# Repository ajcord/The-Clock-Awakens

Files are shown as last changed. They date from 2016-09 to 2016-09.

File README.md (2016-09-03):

The Clock Awakens
=================

Using LEDs and an ESP8266 to make a smart, futuristic Star Wars clock

See [the project page](https://hackaday.io/project/7681-the-clock-awakens)
for details such as the parts list, building instructions, etc.

Uses the [Sunrise-Sunset API](http://sunrise-sunset.org/api) among others.

Setting up the environment
--------------------------

1. Set up the ESP8266 in the Arduino IDE
   ([instructions](https://github.com/esp8266/Arduino))
2. Install the [Time](https://github.com/PaulStoffregen/Time),
   [Adafruit NeoPixel](https://github.com/adafruit/Adafruit_NeoPixel),
   [WiFiManager](https://github.com/tzapu/WiFiManager), and
   [ESP8266Scheduler](https://github.com/nrwiersma/ESP8266Scheduler)
   libraries through the Library Manager
   ([instructions](https://www.arduino.cc/en/Guide/Libraries#toc3))
3. Install the
   [ESP8266FS tool](https://github.com/esp8266/arduino-esp8266fs-plugin)
   located in `lib`
   ([instructions](http://arduino.esp8266.com/versions/1.6.5-1160-gef26c5f/doc/reference.html#uploading-files-to-file-system))
4. Make the necessary changes to `src/firmware/config.h.template`
    and save them in `src/firmware/config.h`
5. Open `src/firmware/firmware.ino` in the Arduino IDE
6. Upload the sketch data by going to Tools > ESP8266 Sketch Data Upload
7. Upload the sketch to the device

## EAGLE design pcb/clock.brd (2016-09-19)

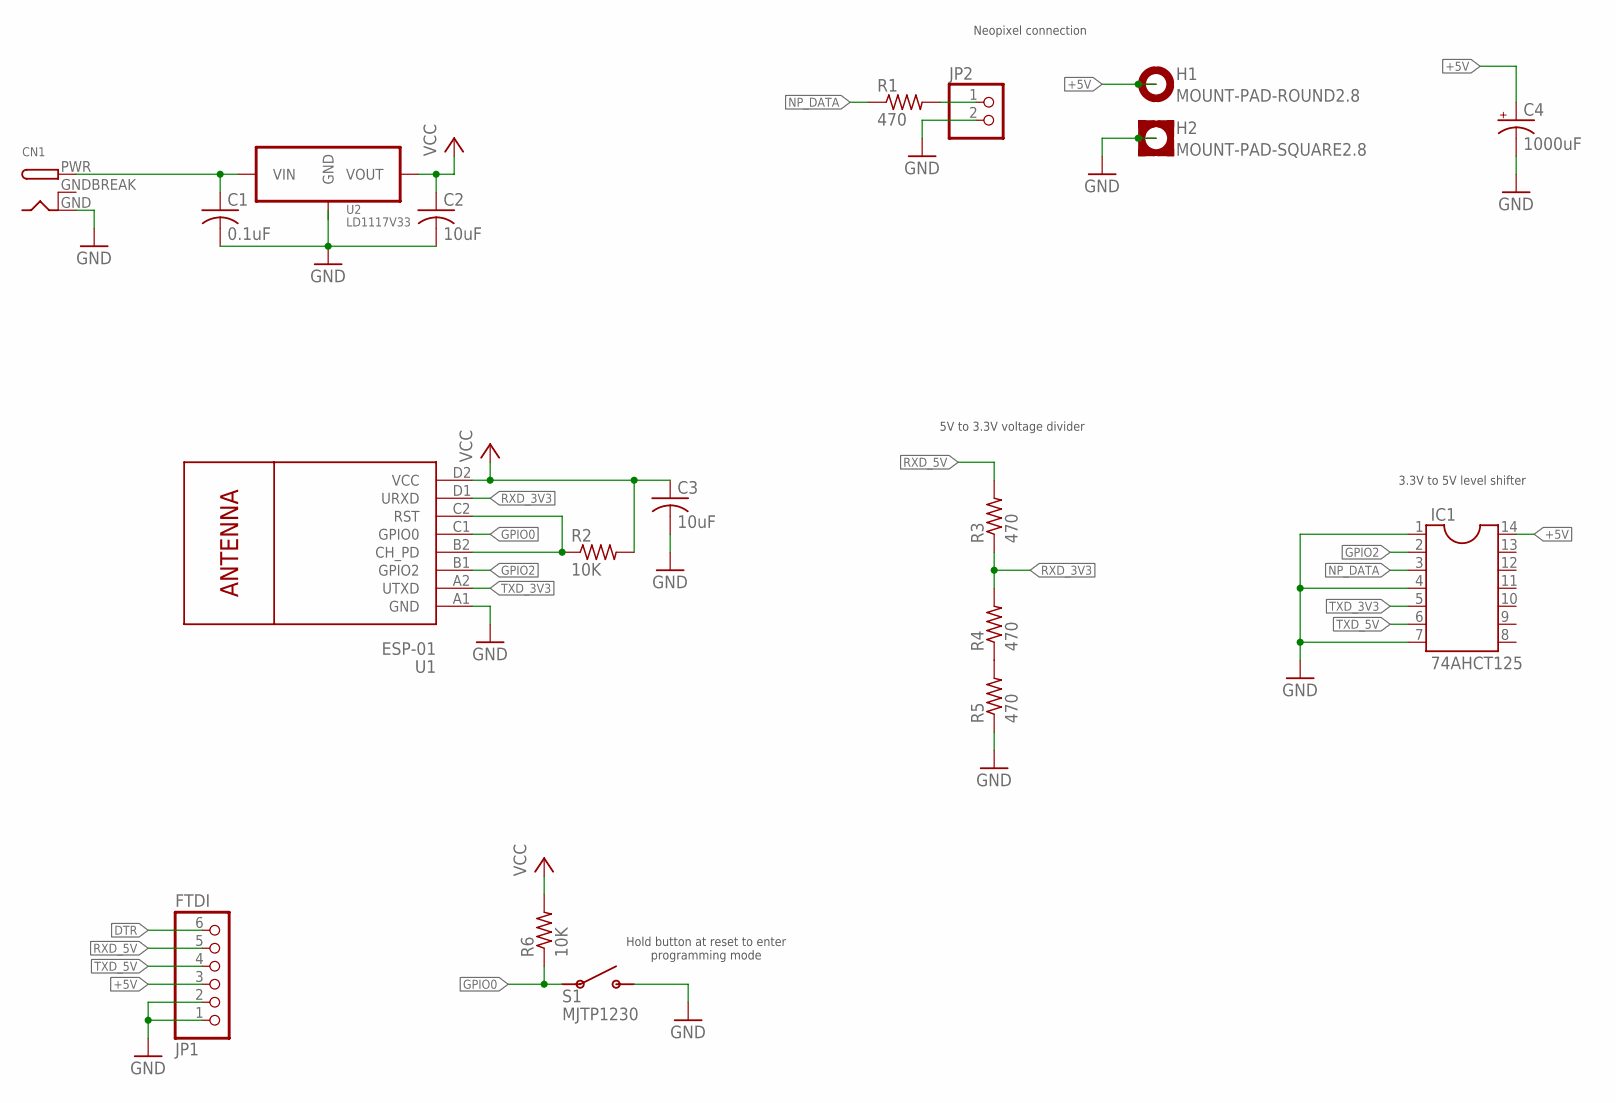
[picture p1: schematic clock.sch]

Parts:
C1: 0.1uF; C025-025X050
C2, C3: 10uF; C025-025X050
C4: 1000uF; E3,5-8
CN1: DCBARRELPTH; DCJACK_2MM_PTH
H1: MOUNT-PAD-ROUND2.8; 2,8-PAD
H2: MOUNT-PAD-SQUARE2.8; 2,8-PAD-SQUARE
IC1: 74AHCT125; DIL14
JP1: FTDI; 1X06/90
JP2: PINHD-1X2; 1X02
R1, R3, R4, R5: 470; 0207/10
R2, R6: 10K; 0207/10
S1: MJTP1230; TACTILE-BUTTON-MJTP1230
U1: ESP-01; WIRELESS-WIFI-ESP-01
U2: LD1117V33; TO-220

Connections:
+5V: C1.1, C4.+, CN1.PWR, H1.B2,8, IC1.14, JP1.3, U2.P$3 (VIN)
DTR: JP1.6
GND: C1.2, C2.2, C3.2, C4.-, CN1.GND, H2.B2,8, IC1.1, IC1.4, IC1.7, JP1.1, JP1.2, JP2.2, R5.1, S1.P$2 (3), S1.P$4 (3), U1.A1 (GND), U2.P$1 (GND)
GNDBREAK: CN1.GNDBREAK
GPIO0: R6.1, S1.P$1 (1), S1.P$3 (1), U1.C1 (GPIO0)
GPIO2: IC1.2, U1.B1 (GPIO2)
unnamed: JP2.1, R1.2
unnamed: R2.1, U1.B2 (CH_PD), U1.C2 (RST)
unnamed: R4.1, R5.2
NP_DATA: IC1.3, R1.1
RXD_3V3: R3.1, R4.2, U1.D1 (URXD)
RXD_5V: JP1.5, R3.2
TXD_3V3: IC1.5, U1.A2 (UTXD)
TXD_5V: IC1.6, JP1.4
VCC: C2.1, C3.1, R2.2, R6.2, U1.D2 (VCC), U2.P$2 (VOUT), U2.P$4 (VOUT)

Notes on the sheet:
Hold button at reset to enter programming mode
5V to 3.3V voltage divider
3.3V to 5V level shifter
Neopixel connection

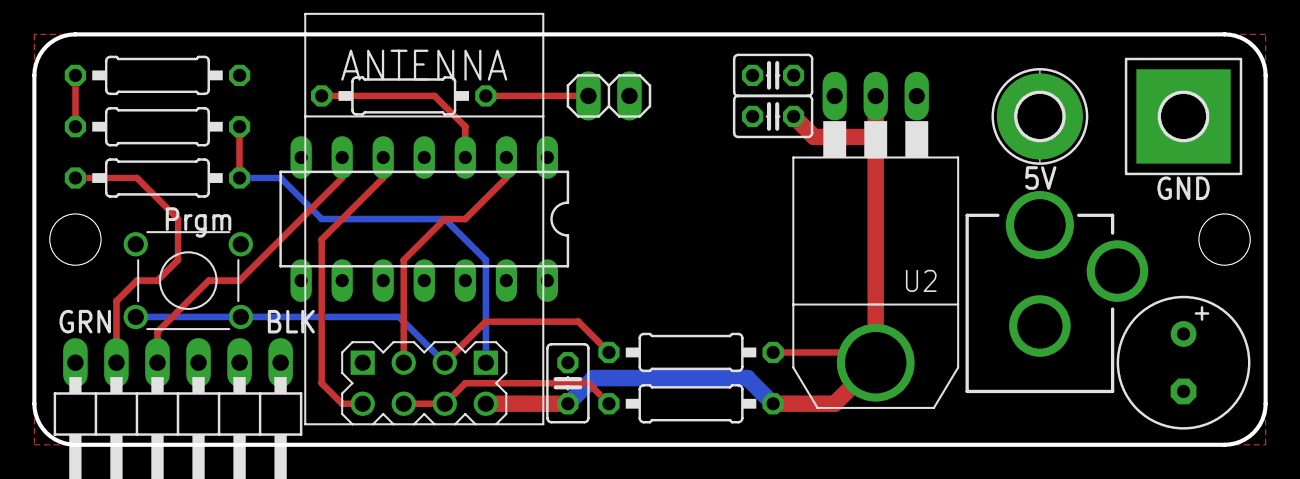
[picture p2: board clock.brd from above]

Board: 2 copper layers, 76.2 x 25.4 mm, 19 parts (0 on the bottom side), 13 nets.

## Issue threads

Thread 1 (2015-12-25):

Allow scheduled color schemes for certain dates

ajcord, 2015-12-25:
E.g. red, white, and blue on July 4th, red and green on Christmas, etc.

ajcord, 2015-12-30:
Could integrate with Google Calendar API to avoid reinventing the wheel

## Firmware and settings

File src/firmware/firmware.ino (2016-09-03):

/**
 * The Clock Awakens: an LED-ringed clock with WiFi
 * Author: Alex Cordonnier
 */

#include <ESP8266WiFi.h>
#include <DNSServer.h>
#include <ESP8266WebServer.h>
#include <ESP8266mDNS.h>
#include <WiFiManager.h>
#include <TimeLib.h>
#include <Adafruit_NeoPixel.h>
#include <EEPROM.h>
#include <Scheduler.h>

#include "config.h"
#include "DataStore.h"
#include "WebServer.h"
#include "Geolocation.h"
#include "InternetTime.h"
#include "ClockDisplay.h"

void setup() {

    delay(5000);
    Serial.begin(115200);
    Serial.print("\n\n");

    printMacAddress();

    WiFiManager wifiManager;
    wifiManager.autoConnect("Clock Setup");

    Serial.println("");
    Serial.println("Connected");

    printWiFiInfo();

    DataStore.begin();
    Geolocation.begin();
    InternetTime.begin(TIME_SERVER, SYNC_INTERVAL);

    Scheduler.start(&web_server_task);
    Scheduler.start(&clock_display_task);

    Serial.println("Ready. Starting scheduler.");

    Scheduler.begin();
}

// Dummy - handled by scheduler
void loop() { }

/**
 * Prints the ESP8266's MAC address for reference.
 */
void printMacAddress() {

    Serial.print("MAC address: ");

    unsigned char mac[WL_MAC_ADDR_LENGTH];
    WiFi.macAddress(mac);

    int i;
    for (i = 0; i < WL_MAC_ADDR_LENGTH - 1; i++) {
        Serial.print(mac[i], HEX);
        Serial.print(":");
    }

    Serial.println(mac[i], HEX);
}

/**
 * Prints info about the WiFi connection.
 */
void printWiFiInfo() {

    Serial.print("Local IP address: ");
    Serial.println(WiFi.localIP());

    Serial.print("Signal strength (RSSI): ");
    Serial.println(WiFi.RSSI());
}

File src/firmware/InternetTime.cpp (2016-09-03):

#include "InternetTime.h"
#include "Geolocation.h"
#include "DataStore.h"
#include <ESP8266WiFi.h>

#define UDP_IN_PORT         2390
#define NTP_OUT_PORT        123
#define TIMEOUT             2000 // ms

#define UNIX_TIME_OFFSET    2208988800UL // Number of seconds from 1900 to 1970
#define NTP_TO_MICROS_RATIO 4295 // Roughly (2^32 / 1000000)
#define PRECISION_TEST_NUM_ITERATIONS   100

// Leap indicator warning bits
enum {
    NTP_LI_NONE,    // No leap second
    NTP_LI_INSERT,  // Last minute has 61 seconds
    NTP_LI_DELETE,  // Last minute has 59 seconds
    NTP_LI_UNKNOWN,   // Clock not synchronized
} NTP_LI;

// NTP mode bits
enum {
    NTP_MODE_RESERVED,
    NTP_MODE_SYMMETRIC_ACTIVE,
    NTP_MODE_SYMMETRIC_PASSIVE,
    NTP_MODE_CLIENT,
    NTP_MODE_SERVER,
    NTP_MODE_BROADCAST,
    NTP_MODE_CONTROL_MESSAGE,
    NTP_MODE_RESERVED_PRIVATE,
} NTP_MODE;

uint32_t extractSeconds(uint64_t ntp) {

    return (uint32_t)((ntp >> 32) & 0xFFFFFFFF);
}

uint32_t extractFraction(uint64_t ntp) {

    return (uint32_t)(ntp & 0xFFFFFFFF);
}

double fixedToFloat(uint64_t ntp) {

    uint32_t seconds = extractSeconds(ntp);
    uint32_t fraction = extractFraction(ntp);

    return (double)seconds + (double)fraction/(1ULL << 32);
}

time_t updateTime() {
    return InternetTime.getTime();
}

void onTimezoneUpdate(DSKey key, int value) {

    Serial.println("Timezone updated!");
    time_t currentTime = updateTime();
    setTime(currentTime);
}

InternetTimeClass::InternetTimeClass() {

    lastSyncTime = 0;
}

void InternetTimeClass::begin(const char* timeServer, time_t interval) {

    hostname = timeServer;

    DataStore.registerObserver(DS_TIMEZONE, &onTimezoneUpdate);

    precision = calculatePrecision();

    // Start listening on the incoming UDP port
    udp.begin(UDP_IN_PORT);

    // Set up time library
    setSyncInterval(interval);
    setSyncProvider(&updateTime);
}

int8_t InternetTimeClass::calculatePrecision() {
    
    unsigned long start = micros();

    for (int i = 0; i < PRECISION_TEST_NUM_ITERATIONS; i++) {
        micros();
    }

    unsigned long end = micros();
    unsigned long totalTime = end - start;
    unsigned long averageTime = totalTime/PRECISION_TEST_NUM_ITERATIONS;

    if (averageTime == 0) {
        averageTime = 1;
    }

    int8_t precision = log2(averageTime/1000000.0);

    return precision;
}

uint64_t InternetTimeClass::getNtpTimestamp() {

    // Comes up with a reasonable NTP-formatted timestamp based on the number
    // of microseconds since startup.
    // Should only be used to compute time intervals, not absolute times.
    // Can't use now() here because it will infinitely recurse.
    return (uint64_t)((double)micros()/1000000.0 * (1ULL << 32));
}

time_t InternetTimeClass::getTime() {

    // Get the timezone first to avoid interfering with NTP calculations
    time_t timezoneOffset = Geolocation.getTimezoneOffset(true);

    // Perform a DNS lookup on the hostname
    IPAddress ip;
    int dnsError = WiFi.hostByName(hostname, ip);
    if (dnsError != 1) {
        Serial.print("Could not resolve hostname '");
        Serial.print(hostname);
        Serial.print("'. Error: ");
        Serial.println(dnsError);
        return 0;
    }

    sendRequest(ip);
    uint64_t clientTransmitTime = getNtpTimestamp();

    long lastRequestTime = millis();
    int numberOfTimeouts = 0;

    // Wait for a response
    while (!udp.parsePacket()) {

        if (millis() - lastRequestTime > (TIMEOUT << numberOfTimeouts)) {

            Serial.println("NTP request timed out.");
            sendRequest(ip);
            clientTransmitTime = getNtpTimestamp();
            lastRequestTime = millis();
            numberOfTimeouts++;
        }

        yield(); // Reset the watchdog
    }
    
    ntp_packet_t response;
    uint64_t clientReceiveTime = getNtpTimestamp();
    udp.read((char*)&response, sizeof(ntp_packet_t));
    time_t currentTime = parseResponse(response, clientTransmitTime, clientReceiveTime);

    // Convert from UTC to localized time
    time_t localizedTime = currentTime + timezoneOffset;

    Serial.print("The current local time is: ");
    Serial.println(localizedTime);

    return localizedTime;
}

void InternetTimeClass::sendRequest(IPAddress ip) {

    ntp_packet_t packet;
    memset(&packet, 0, sizeof(ntp_packet_t));

    // Build the NTP packet
    packet.leap = NTP_LI_UNKNOWN;
    packet.version = 4;
    packet.mode = NTP_MODE_CLIENT;
    packet.stratum = 16;
    packet.poll = 6;
    packet.precision = precision;
    packet.ref_id = ip;
    packet.ref_ts = lastSyncTime;
    packet.origin_ts = __builtin_bswap64(getNtpTimestamp());

    udp.beginPacket(ip, NTP_OUT_PORT);
    udp.write((char*)&packet, sizeof(ntp_packet_t));
    udp.endPacket();
}

time_t InternetTimeClass::parseResponse(ntp_packet_t & packet,
    uint64_t clientTransmitTime, uint64_t clientReceiveTime) {

    // Remember to convert big-endian network values to
    // little-endian host values
    uint64_t serverReceiveTime = __builtin_bswap64(packet.recv_ts);
    uint64_t serverTransmitTime = __builtin_bswap64(packet.trans_ts);

    // The number of seconds we are ahead of the server
    uint64_t offset = ((serverReceiveTime - clientTransmitTime) +
                    (serverTransmitTime - clientReceiveTime))/2;

    // The round-trip delay on the network, assuming symmetry
    uint64_t delay = ((clientReceiveTime - clientTransmitTime) -
                    (serverTransmitTime - serverReceiveTime))/2;

    uint64_t currentTime = serverTransmitTime + delay;

    lastSyncTime = currentTime;

    // For the highest accuracy, wait until the second is just changing
    // before returning the time since it gets rounded to seconds by TimeLib.h
    uint64_t timeElapsed = getNtpTimestamp() - clientReceiveTime;
    uint64_t timeSinceSecondStarted = (currentTime + timeElapsed) & 0xFFFFFFFF;
    uint64_t timeLeftInSecond = 0x100000000 - timeSinceSecondStarted;
    time_t microsecondsToWait = (time_t)(timeLeftInSecond / NTP_TO_MICROS_RATIO);
    delayMicroseconds(microsecondsToWait);

    // Convert the wire time, which uses an epoch of 1900,
    // to Unix time, which uses an epoch of 1970.
    currentTime = currentTime + timeElapsed + timeLeftInSecond;
    time_t unixTime = extractSeconds(currentTime) - UNIX_TIME_OFFSET;

    return unixTime;
}

InternetTimeClass InternetTime;

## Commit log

2016-09-03 Updated for Arduino IDE 1.6.10
2016-09-03 Added scheduler, waiting on library to stabilize
    [WebServer.cpp, firmware.ino]
2016-09-03 Fixed panics, but web server always refuses connections due to clock display task
    [WebServer.cpp, firmware.ino]
2016-09-03 Removed backward MAC address workaround
    [firmware.ino]
2016-09-03 Added empty PCB design
    [clock.brd, clock.sch]
2016-09-04 Started PCB
    [clock.brd, clock.sch]
2016-09-18 Added button
    [clock.brd, clock.sch]
2016-09-19 Linearized the board layout
    [clock.brd]
2016-09-19 Improved layout to make room for light sensor
    [clock.brd, clock.sch]

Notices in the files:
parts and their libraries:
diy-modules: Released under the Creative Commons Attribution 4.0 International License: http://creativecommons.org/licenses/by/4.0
